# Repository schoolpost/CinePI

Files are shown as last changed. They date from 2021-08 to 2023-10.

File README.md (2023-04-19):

# CinePI V2: OpenSource Cinema Camera using Raspberry Pi
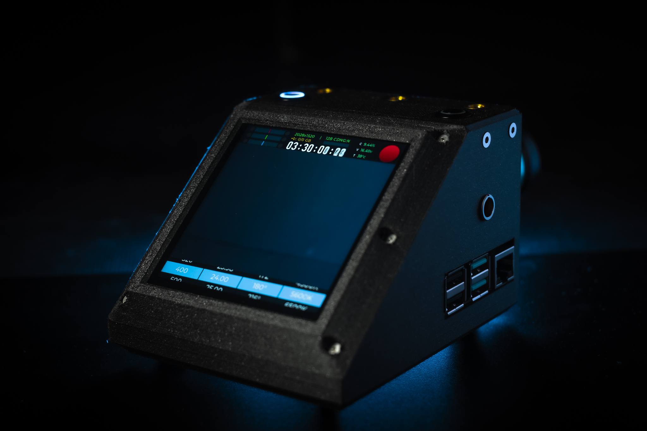
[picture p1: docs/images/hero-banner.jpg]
Banner

&nbsp;

# Introduction

The CinePI V2 is an OpenSource Camera design utilzing off-the-shelf / DIY hardware & software from vendors including: Raspberry Pi, Pimoroni, Adafruit, Sparkfun, etc...

The purpose of this repository and it's accomanying resocures is primarly to act as a template / starting point for your own design. CAD files are included for you to modify the enclosure to your needs, feel free to experiment with the parts used; use a different set of buttons, RTC, display, etc... the only components that cannot be changed are the Raspberry Pi 4B and the High Quality Camera Module. 

> ## Notice 
> 
> This design makes a number of modifications to hardware, as such is not recommended for those not comfortable with a soldering iron.
> 
> Warranties may be void. I am not responsible for any damages that accompany hardware modifications. 

# Features

- Super8 Sized Sensor ( Sony IMX477 )
- 12-bit CinemaDNG Recording
- 4.0" High Res Touch Screen Interface
- Internal High Capacity Battery 
- Real time clock 
- USB 3.0 External SSD Recording
- 1/4" Mounting Points
- 40mm Noctua Cooling System 

# Guide

Refer to the Wiki section for in-depth guide on hardware assembly and software installation. 

# References

CinePI Project Account | [Github Page](https://github.com/cinepi)

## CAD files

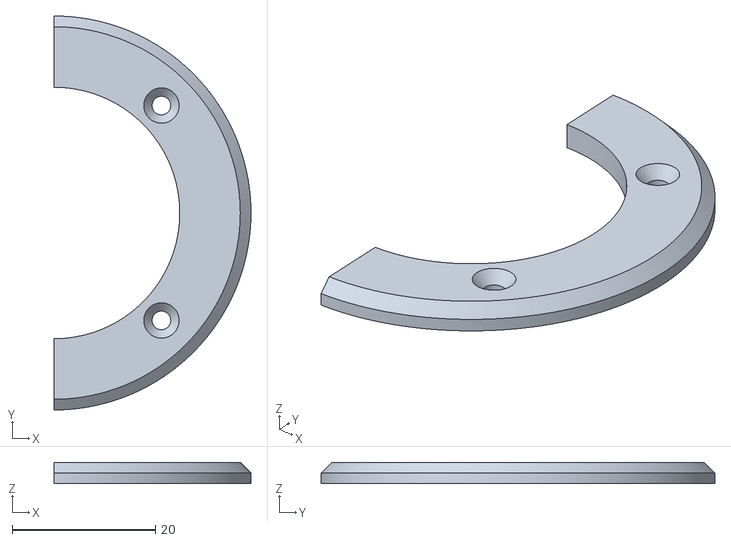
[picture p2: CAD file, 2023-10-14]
hardware/enclosure/turret_cover_plate_001.stl
27.5 x 55.0 x 3.00

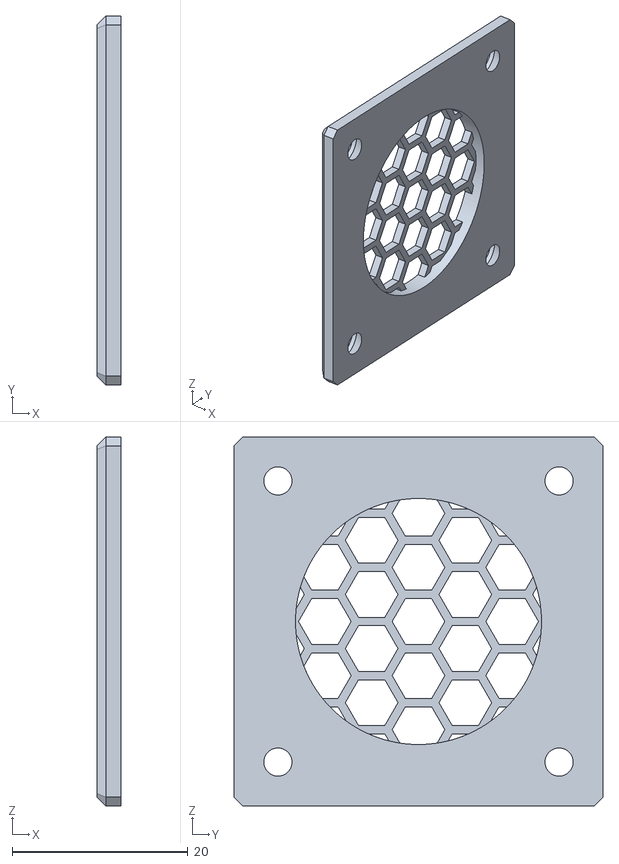
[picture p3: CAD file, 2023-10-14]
hardware/enclosure/fan_grill_001.stl
2.70 x 42.0 x 42.0

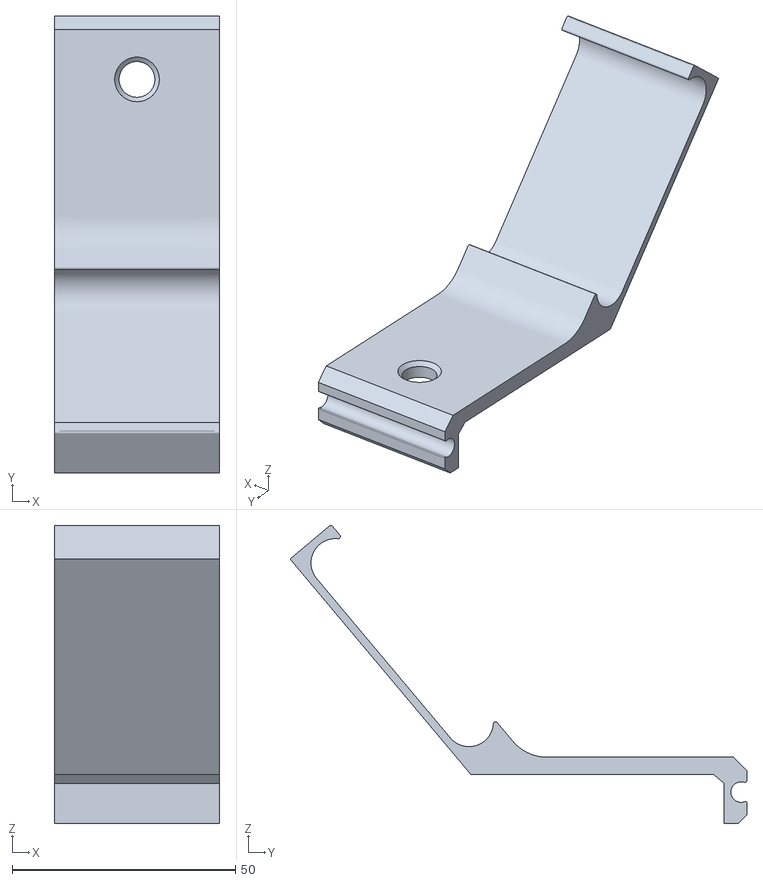
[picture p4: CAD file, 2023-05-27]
hardware/enclosure/t5_holder_001.stl
37.0 x 102.4 x 66.8

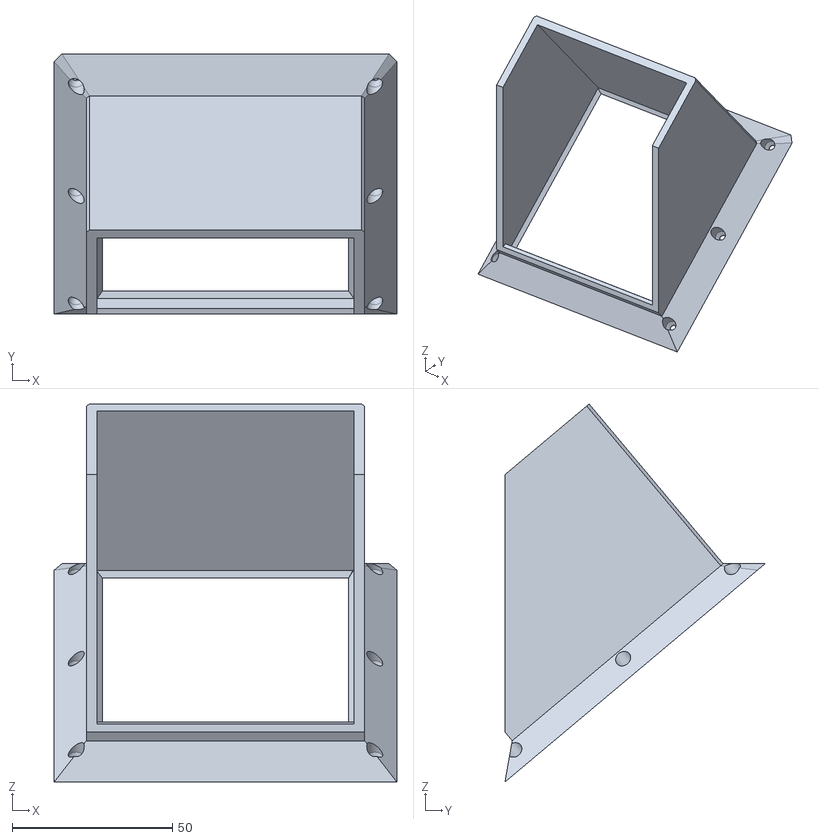
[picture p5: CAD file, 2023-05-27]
hardware/enclosure/sunhood_001.stl
106.8 x 81.1 x 117.8

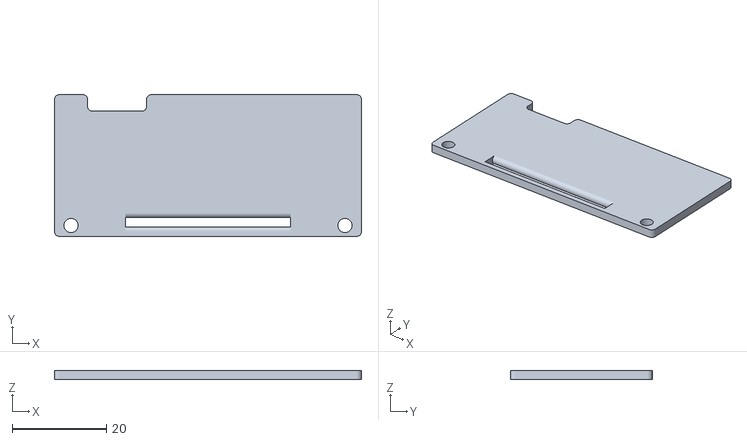
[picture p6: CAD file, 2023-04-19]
hardware/enclosure/ribbon_retention_bracket_002.stl
65.0 x 30.0 x 2.00

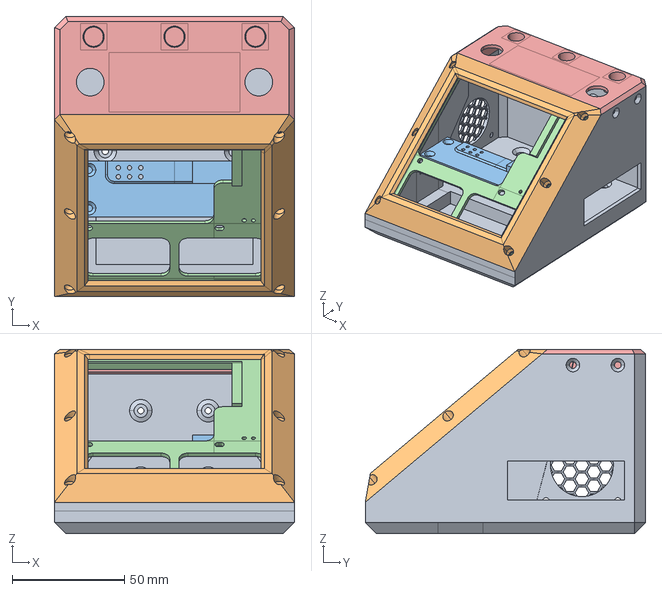
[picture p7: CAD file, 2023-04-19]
hardware/enclosure/CinePI_V2.stp
106.8 x 124.8 x 82.0 mm

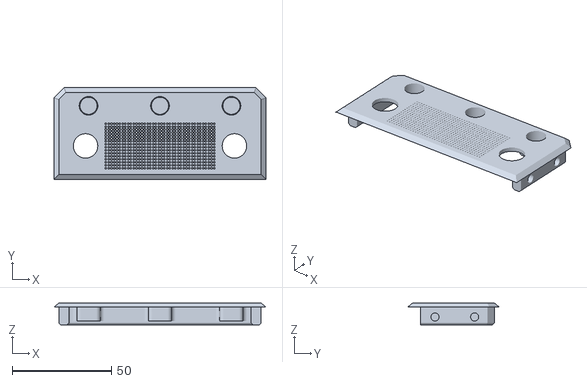
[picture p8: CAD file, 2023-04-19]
hardware/enclosure/top_plate_001.stl
106.8 x 46.1 x 11.0

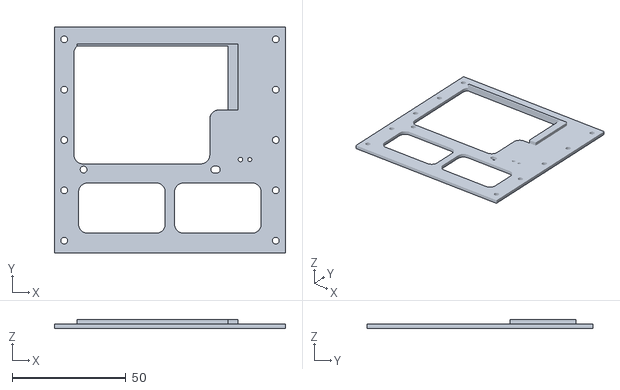
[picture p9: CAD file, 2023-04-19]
hardware/enclosure/hyperpixel_bracket_002.stl
101.6 x 99.6 x 4.00

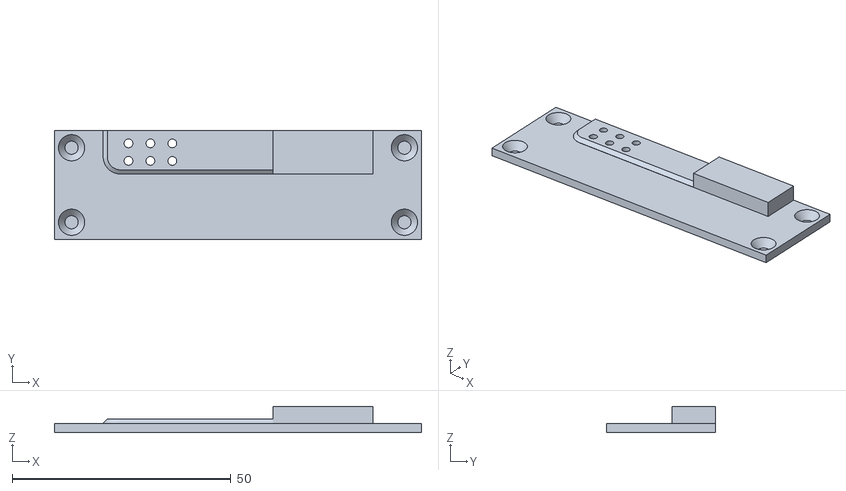
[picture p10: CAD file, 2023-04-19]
hardware/enclosure/battery_retention_plate_002.stl
83.8 x 25.0 x 6.00

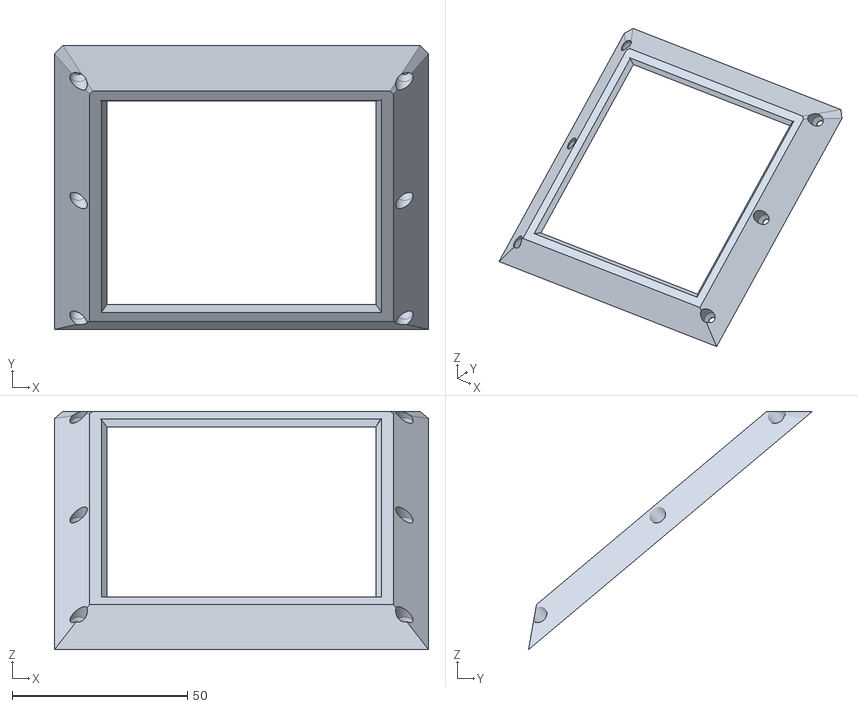
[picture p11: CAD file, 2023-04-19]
hardware/enclosure/screen_plate_001.stl
106.8 x 81.1 x 68.0

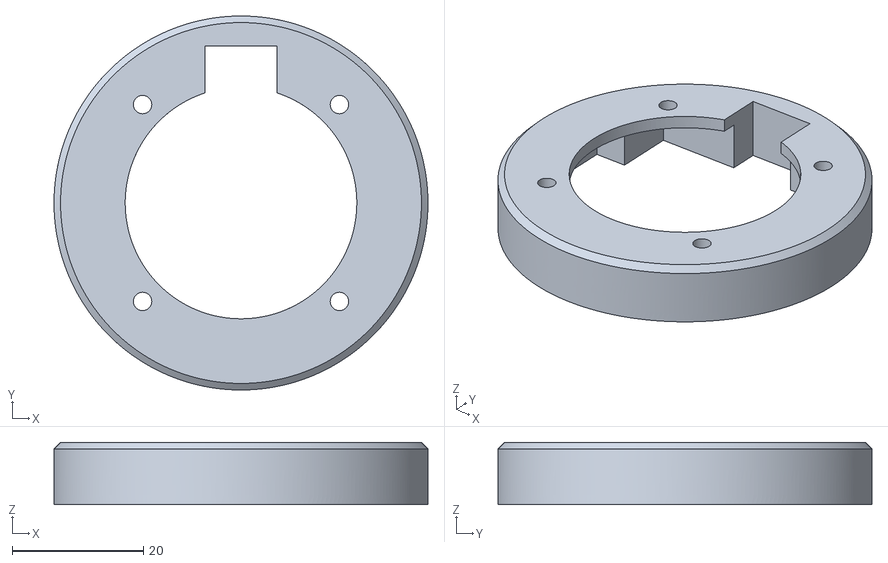
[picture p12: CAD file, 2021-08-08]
hardware/enclosure/cinepi_lens_turret_v1.stl
57.0 x 57.0 x 9.50

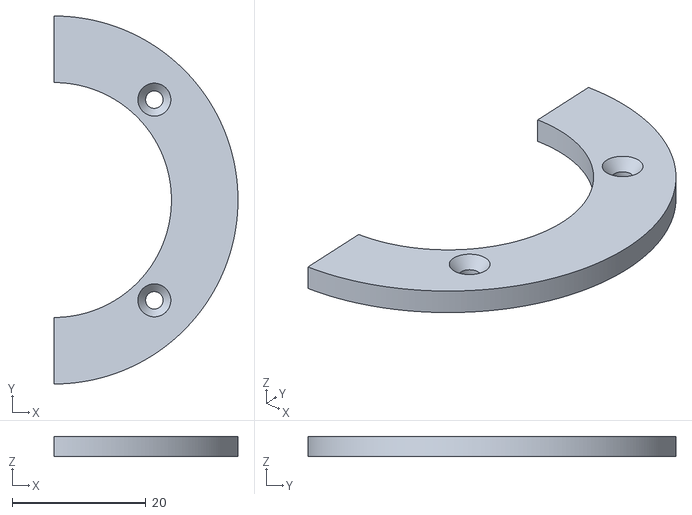
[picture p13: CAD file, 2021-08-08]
hardware/enclosure/cinepi_lens_turret_cover_right.stl
27.5 x 55.0 x 3.00

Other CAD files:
hardware/enclosure/cinepi_lens_turret_cover_left.stl

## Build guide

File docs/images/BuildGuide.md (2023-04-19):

| Item | Quantity | Link | Price |
|---|---|---|---|
| Raspbery Pi 2/4/8GB | 1 | https://www.digikey.com/en/products/detail/raspberry-pi/RASPBERRY-PI-4-MODEL-B-8G/12159401 | $35-$75 |
| Raspberry Pi HQ Camera | 1 | https://www.digikey.com/en/products/detail/raspberry-pi/SC0818/12339164 | $50.00  |
| Pimoroni Hyperpixel Square 4.0" | 1 | https://www.digikey.com/en/products/detail/pimoroni-ltd/PIM470/10329005 | $76.50  |
|  Zero2GoOmini R2 | 1 | https://www.digikey.com/en/products/detail/pimoroni-ltd/zero2go-omini-r2/15851372 | $22.00  |
| | | | |
| PCF8574 | 1 | https://amz.run/6bhj | $1.57 |
| PCF8523 | 1 | https://www.digikey.ca/en/products/detail/adafruit-industries-llc/3295/6238007 | $6.95 |
| CR1220 | 1 | https://amz.run/6bhs | N/A |
| | | | |
| Dupont Wires | | https://www.aliexpress.com/item/1005002000655439.html | |
| 40-pin FFC Cable | 1 | https://www.digikey.ca/en/products/detail/adafruit-industries-llc/4933/14291405 | |
| 40-pin GPIO FFC Extender Angled Male | 1 | https://www.digikey.ca/en/products/detail/adafruit-industries-llc/4904/14205155 | |
| 40-pin GPIO FFC Extender Angled Female | 1 | https://www.digikey.ca/en/products/detail/adafruit-industries-llc/4905/14205159 | |
| SparkFun QWIC Breakout | 2 | https://www.digikey.ca/en/products/detail/sparkfun-electronics/DEV-14495/7942483 | |
| QWIC Cables | | https://www.digikey.ca/en/products/detail/sparkfun-electronics/PRT-17260/13629028 | |
| | | | |
| Notcua NF-A4x10 5V 3-pin | 1 | https://amz.run/6bht | |
| 12mm Blue LED Button | 1 | https://www.aliexpress.com/item/33014419878.html | |
| 12mm Red LED Button | 1 | https://www.aliexpress.com/item/33014419878.html | |
| 7-pin LEMO Female | 1 | https://www.aliexpress.com/item/1005004949203075.html | |
| | | | |
| NCR18650B | 4 | https://www.18650batterystore.com/en-ca/products/panasonic-ncr18650b | |
| Micro JST connector/cable | | https://www.aliexpress.com/item/32704408939.html | |
| PVC Shrink | | | |
| 4S BMS | 1 | https://www.aliexpress.com/item/1005005389852465.html | |
| | | | |
| | | | |
| | | | |

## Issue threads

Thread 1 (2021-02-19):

Source Code?

eat-sleep-code, 2021-02-19:
Csaba --

I have been following your video examples on the Pi Forums and would love to incorporate your video capture logic into my own [camera program](https://github.com/eat-sleep-code/camera) (which has on screen controls, etc.).

I am currently printing Gen 3 of my camera which has a 5" hinged capacitive touch screen, top handle, multiple cold shoe mount screws, active cooling, and room for up to a 20,000mah battery.

schoolpost, 2021-02-28:
Check the releases section, just released the first alpha version. a lot of it is explained there.

peternewman, 2021-11-11:
Hi @schoolpost ,

On the latest release it says:

> source code will be available in the main repository. Due to the layers / complexity of creating a "Camera" through a traditional Operating system not every component of the software can be/will be referenced in the source. Filesystem drivers, boot configurations, etc.. are all examples of the additional layers that are required to make a functional camera and these layers will be left partially obfuscated from the source to reduce the number of dependencies and shear overall size of the code base. These components will be mentioned in documentation to give users the knowledge of their existence and how they can be modified/used.

Where is say the Python bmdproxy script currently being developed or the source code managed? What would someone open a pull request against if they wanted to make a change? I'm just curious about it, so don't want to have to download a 2GB file and flash it to a Pi or possibly mount it as loopback just to have a look at a few hundred kB of Python.

Closed 2021-03-06.

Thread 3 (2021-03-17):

Bluetooth control

pu3lkah, 2021-03-17:
Hi, I can't manage to connect the raspberry pi to my android device via bluetooth, is there anything I should configure on the board first ?

schoolpost, 2021-03-19:
What application are you trying to connect it with? You need to use an app that is designed for Blackmagic Cameras.

pu3lkah, 2021-03-20:
I'm using the control black magic camera app for android. Tom antos showcased it in one of his videos by using it with a bmpcc4k and it works flawlessly, but on my phone, as you can see I can only find one device (I'll add a screenshot) and I'm unable to pair to it, even after clearing the bluetooth and the app cache, restarting my phone and/or the pi, etc...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

schoolpost, 2021-03-22:
> I'm using the control black magic camera app for android. Tom antos showcased it in one of his videos by using it with a bmpcc4k and it works flawlessly, but on my phone, as you can see I can only find one device (I'll add a screenshot) and I'm unable to pair to it, even after clearing the bluetooth and the app cache, restarting my phone and/or the pi, etc...!
> [Edit, I also try formatting the sd card and reinstalling cinepi on it but the results are the same]

The Bluetooth service starts up when booted so nothing you have to do on the user side.

This will be something to look into, I was under the assumption most of these applications would connect with a similar procedure, but seems not to be the case. I do not have any android device to test with at the moment, so you may have to experiment /tinker with it yourself for the time being.

If you want to look at the source go to the controls-thread folder in the home directory of the installation.

pu3lkah, 2021-03-23:
Okay, thanks a lot, i'll try getting my hands on an ios device to test it out. Do you think there might be a way to control the settings with a wired controller ? Either mouse and keyboard or small arduino controller ?

nocantsin, 2021-05-08:
The Android app _My Camera Controller_ (gratis w/ ads) works with the CinePi:
https://play.google.com/store/apps/details?id=com.taskdesigns786.android.mycameracontroller&hl=en_US&gl=US

Leoba2700, 2021-06-22:
hi i have the same issue but with the bluetooth+ for Blackmagic app on my iPhoneX. I Cant find any raspberry bluetooth connection even in my bluetooth option. my raspberry pi 4 is brand new, there is nothing to activate in order to make it work ?

schoolpost, 2021-06-23:
> hi i have the same issue but with the bluetooth+ for Blackmagic app on my iPhoneX. I Cant find any raspberry bluetooth connection even in my bluetooth option. my raspberry pi 4 is brand new, there is nothing to activate in order to make it work ?

The Bluetooth service auto starts when the Pi is booted. I also use a iPhoneXR with Bluetooth+ and have not had the same issue you are having. Go to the Bluetooth settings of your iPhone and if you see your raspberry pi already paired, you should try to "forget device" maybe that will help.

Leoba2700, 2021-06-23:
that's weird... the thing is that the raspberry pi doesn't even show up in my bluetooth settings

nocantsin, 2021-06-23:
I am having the same issues - both the Android and the recommended iOS app.

schoolpost, 2021-06-23:
Will need to investigate this, may have been a change that happened on the IOS Application side that breaks compatibility.

Leoba2700, 2021-06-25:
is it possible to change the settings without the apps ? if yes, what is the way to do it ?

schoolpost, 2021-06-25:
> is it possible to change the settings without the apps ? if yes, what is the way to do it ?

Yes, you could create your own scripts that will control camera settings, but you will need to decide to use bluetooth, wifi or physicals controls to obviously interact with the Pi.

You need to look into v4l2-ctl

It's a command line utlity that allows you do control the settings of a v4l2 device ( /dev/video0 ) in this case. It's a bit more low level, you wont be changing "shutter speed" or "frame rate" but if you read up on what each does you should get an idea.

Leoba2700, 2021-06-25:
unfornatly I don't think I have the capacity to create my own script maybe ill try with an other app

schoolpost, 2021-06-25:
> unfornatly I don't think I have the capacity to create my own script maybe ill try with an other app

I have a development version that is newer than what is posted here on github, that one works just fine with Bluetooth+ app. I don't have time right now to upload it,  but I will try to do that soon.

Otherwise, yes your best luck would be to see if some other apps might work.

schoolpost, 2021-09-25:
Should be addressed in the latest 1.0.1 release. Please test and report back.

tallmansixfour, 2021-09-29:
Hey schoolpost,

having trouble connecting with any app on android. tried Control Blackmagic Camera (lost $12 - no returns), Blackmagic BlueConnect (goodbye $12), Blackmagic Camera control (free). tried clearing storage and cache on individual apps. nope. is there another cache to clean somewhere?

installed 1.0.1 Still shows v.1.0.0 Is something wrong here?
used 20210920_022913_pi_clone.img

I understand it's alpha, but could you test with one known-good Android app please?

thanks

Chris in Montreal

schoolpost, 2021-09-30:
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

Hi Chris,

Unfortunately I do not have any android devices to test with. Can you test with an iOS device?
This will help narrow down if it's a device specific problem or something else.

tallmansixfour, 2021-09-30:
thanks for the reply. i did try the free options first, but noting. My Camera Controller shows a device (code) then shows connecting and even initializing, but then nothing. paid options usually offer a refund for 5-10 minutes, but i the case of the two i mentioned, no such option was presented. im eager to get my project working with your system, raspivid pales in comparison. do you have a Patreon?

nils1976, 2022-01-24:
Hi guys,

First of all really cool project....
Managed to make that work in less than an hour? But also have the BT error.
My "camera" is also complaining, that it is v 1.0.0

I can connect to the pi via ssh. But was not able to find where the defaults are set. Therefore it is not usable at the moment.

How can I provide help to make the BT stuff work? Tried different apps und different platforms....(android and IOs)
but with no luck. Is there kind of an log? Didn't find that in /var/log....
where is the patreon link? or Paypal...? Think you need beer or coffe support!!

Also i doesn't work with the DSI-connected Display from raspberry...not a big thing, but maybe someone like to know.
It there a restriction in resolution?

But what I can say: Using a passive CSI to HDMI (not converting to HDMI!!!!!) adapter works fine with a 2m cable.
Which makes it also more intersting for independent filming, as you can put the "recorder" away from the head.
Like our plan is: putting the camera on a handlebar of a bike....having the recoder in the back or bag....;-)

kind regards Nils

schoolpost, 2022-01-24:
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

Very kind of you Nils, glad you can find a use case for this project.
You can donate to my paypal here:
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

As far a bluetooth control is concerned, It seems to me that only application that works right now is a paid app called "Bluetooth+" that is available on IOS. This is the app I did all my testing/development with. I did not realize that although I was reverse engineering a standard protocol, some applications do not seem to detect it.

The way you control the camera's settings is mostly through v4l2-ctl. You can ssh into the pi and list the available controls and mess around with them to see how it changes the image. But also I'm looking into a better way to do this.

I was recently looking to attach a display to the camera, over DPI using the GPIO pins; but even this proved to be a problem and it seems like the reason for this has to do with the i2c being used by the camera module and therefore it claims the i2c so no other peripheral that uses i2c can be used. ( simplification )

Would love to see some footage you film when you are done with your setup.

Csaba Nagy

tallmansixfour, 2022-01-24:
Thanks for the update. Made a donation - hope it helps. There is great
potential here. I want to use the setup for stereoscopic fiming.
Chris

On Mon., Jan. 24, 2022, 5:15 p.m. Csaba Nagy, ***@***.***>
wrote:

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

nils1976, 2022-01-25:
Ok now it is getting weird.....I was asking for a link to donate....some else donates....but I also....
I was using the bluetooth+ app at first time.....doesn't work....
Yes I can confirm, that it boots with DSI connected, can also see the overlay from the mmal stuff, than it runs into normal boot login, I think at the point where the sensor get initialized....anyhow....not a big thing, ordered a 7" Display yesterday.
If you are interested in getting i2c data, I have a little USB-analyzer...
So I will try the app again...it is always complaining the I should remove the camera from the bluetooth settings (can even put it in there, because it is not showing up in the OS....but in the app)

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
.

Let me know if I can do something from my side. Logs/debug output etc....

Btw: If I don't want to use XFS, what is the next best choice? Ntfs? or HFS?

If we can manage to get that work, you will get footage. Our apprentice will generate some....

nils1976, 2022-01-28:
Hey there,
is there a simple way to start the camera, lets say 2k 25p? I see that i can set the vertical blanking...but not shure if I exactly hit the 25p:  v4l2-ctl -d /dev/video0  --set-ctrl vertical_blanking=1500 gives me a 25p, not shure if this is on the point.......but I think it also depending on the resolution....I am not that python guy/programming guy, so a feedback would be nice..
I understood that your scripts reads the settings that are actual....an it is fine for me to set that manual, without using the app

Regards Nils

schoolpost, 2022-01-28:
> Hey there, is there a simple way to start the camera, lets say 2k 25p? I see that i can set the vertical blanking...but not shure if I exactly hit the 25p: v4l2-ctl -d /dev/video0 --set-ctrl vertical_blanking=1500 gives me a 25p, not shure if this is on the point.......but I think it also depending on the resolution....I am not that python guy/programming guy, so a feedback would be nice.. I understood that your scripts reads the settings that are actual....an it is fine for me to set that manual, without using the app
>
> Regards Nils

Hi Nils,

Yes, I also would need to review the code to confirm this, but I do believe it is the VBLANK that needs to be adjusted for this.

There is some more information about this here when I was also investigating how it works: https://forums.raspberrypi.com/viewtopic.php?p=1789990#p1789990

Regards,

Csaba Nagy

Closed 2023-04-19.

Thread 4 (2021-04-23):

Limited record time + weird files

pu3lkah, 2021-04-23:
Hi, so i have now been using your program for a few weeks on my raspberry/super 8 hybrid, and i love it. Apart from the bluetooth control on android I've already reported, i've ran into two other issues. The main one being that i cannot record more than approximately 40 seconds of video, and the more I record the shorter my record time get. At first i was using a cheap pny ssd, and I thought it might be that the drive wasn't fast enough. So I switched to a 500go samsung t7, which should be even faster than what the pi can output through usb 3 (i'm using a rpi 4b 4go ram), but i'm still running into the same issue. Both disks were formatted to exfat, I don't know if it comes from the disk or the board, if it should have more ram or if overclocking it a bit more might help. (I don't know if you ever ran into a similar issue, since in your video you're saying that you also are using a 4gb version)
The second one, which is not a big issue for me but i thought it might be worth letting you know, is that the files i record show as weird black images with color lines as if every file were corrupted (see screenshots) and it says that the image size is 128*67px. Also I cannont open it in premiere pro (it says "file not supported or damaged". But, where it get really weird, (but also the reason why I'm saying it's not a big issue) is that I can open the files in camera raw, and there i have all of my dng files, full size, perfectly fine, that i can then export in jpegs or png frame sequence. I have no idea what might be causing it, and i already tried re-flashing the sd card on the pi.
Thank you for your time and keep up the great work, it helped me tremendously in my projects ! I wish i could help with those issue, unfortunately i don't know much about programming. Hope those reports can help you fixing as many issues as you can in the future, and if i can do any tests for you than could be any help, let me know.
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

schoolpost, 2021-04-24:
Really glad you've found the project useful. If you have any footage you are willing to share, please do. Love to see how it's being used. You can post it on the raspberry pi forums if you are a member there: https://www.raspberrypi.org/forums/viewtopic.php?f=43&t=296776

To address your points, they are also issues I've faced myself.

The limited record time is the biggest hurdle because It's very complicated and a fix isn't exactly trivial. Yes a Fast SSD helps and I've tried many ( CFAST to USB3 adapter, Samsung T5 SSD, NVME to USB 3.0 adapter ) but these don't seem to be the actual bottleneck. It really comes down to how frames are being written to disk, which right now happens through write caching in RAM. That is why you have ~40seconds of record time ( 4GB model ) while for myself I have used the 8GB model and consitently get ~90seconds. So basically It seems the writing of the frames to disk is still not efficient enough, because as soon as the RAM get's full and it has to write to disk directly it is not fast enough. Not exactly sure how this can be addressed, but I'll be investigating asking around to see how it can be fixed.

The weird colored thumbnails is actually to be expected. Basically while this was in Alpha and especially while the Limited record time issue exists I didn't want to add any extra latency to writing a frame so I create an "empty thumbnail" so that is why it is kind of random. This is can be fixed with relative ease. But not looking to implement till the other issues are not solved.

schoolpost, 2021-04-28:
>  The main one being that i cannot record more than approximately 40 seconds of video, and the more I record the shorter my record time get.

May have solution soon, will keep you updated.

pu3lkah, 2021-05-20:
Thanks for all the updates, I actually tried formatting the disk in ext4, and I have much better record time. I haven't tested extensively yet, so I don't know what is the exact time limit, but with a samsung t7 in ext4, i was able to record clips up to 2 minutes. Probably would be able to record a bit more, haven't tried recording to its limits yet.

Tiramisioux, 2021-06-18:
Hi! Tried out the Samsung T7 500 MB drive in ext4 and was able to record a 24 minute clip @ 25 fps.

pu3lkah, 2021-06-18:
Nice to know it can be pushed so far ! Personally few minutes of clips at a time is fine by me. (Oh and I have the 4gb version so i probably wouldn't be able to record such long clips, I should test and see what the limitations are)

Tiramisioux, 2021-06-19:
I agree, a couple of minutes is enough. :) But recording now seems stable and consistent, which is a huge step forward!

Closed 2021-06-28.

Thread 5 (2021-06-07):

Unrecognized external SSD

jineshkunj, 2021-06-07:
Hello, thank you for making Cinepi
Please bear with me that my mother tongue is not English.

I cannot be identified successfully when I use both SSDs
One is Samsung T5 500g, the other is Lexar 500g
It should all be usb 3.1 specifications.

But I don't know why, the SSD cannot be recognized.
Excuse me, how can I solve this problem
Thank you very much, thank you :)

schoolpost, 2021-06-07:
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

When you format the SSD make sure the volume name is "RAW" otherwise it will not be mounted.

This will be changed in a later version so it can be anything.

Closed 2021-06-10.

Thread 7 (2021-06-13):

Lower ISO values than 100

Tiramisioux, 2021-06-13:
Is it possible to add lower ISO values to the available ones? Would like to try values 6,12 and 50. Can it be done solely in proxy.py, or do I have to manipulate other files as well?

schoolpost, 2021-06-13:
> Is it possible to add lower ISO values to the available ones? Would like to try values 6,12 and 50. Can it be done solely in proxy.py, or do I have to manipulate other files as well?

ISO, like many of the other controls is a computed value. If you wish to control it at the lowest level, ISO in this case would be the analouge_gain setting that is exposed by the V4L2 camera component. If my memory is correct, with the current way ISO is computed; 100 ISO is equal to 0 Analouge_gain. So 100 is the lowest ISO setting in this case.

You can look into the _v4l2-ctl_ utility to see how you can control the camera settings directly.

Proxy.py is essentially using that utility to set/get camera settings.

schoolpost, 2021-06-14:
This thread here may also be of some help in understanding how to control the camera through V4L2: https://www.raspberrypi.org/forums/viewtopic.php?f=43&t=281994&p=1789990#p1789990

Tiramisioux, 2021-06-14:
Thanks! Have been experimenting with v4l2-ctl and tried to change the multiplier in proxy.py from 100 to, for example 25 (for an ISO range of 25-556). But the camera still gives me 100 as the lowest ISO value. Am I understanding it correctly that this  could give an ISO range of 25 - 556?

schoolpost, 2021-06-14:
> Thanks! Have been experimenting with v4l2-ctl and tried to change the multiplier in proxy.py from 100 to, for example 25 (for an ISO range of 25-556). But the camera still gives me 100 as the lowest ISO value. Am I understanding it correctly that this could give an ISO range of 25 - 556?
>
> Or is the analogue_gain 0, giving a result similar to ISO 100 a limitation in the camera? That it's sensitivity can't be set to nil?

If you want to change the display of the ISO on the liveview you also need to change the render.c file in the mmal_ui_render folder. in that file is a gain_to_iso function you will need to change that to reflect your own calculation of ISO.

At the end of the day, the implementation I have in place is my best interpretation of how to calculate ISO.

Also read this: https://www.strollswithmydog.com/pi-hq-cam-sensor-performance/

Closed 2021-06-28.

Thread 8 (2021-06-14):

cinePI boot on terminal

eljuligallego, 2021-06-14:
Hi,

I setup the hardware as user guide says, flash sd connect HQ camera, connect "RAW" ssd and boot the 32GB sd card in a raspi 4 4GB.

after the cinePI splash screen the terminal appears. tried to start the terminal with the credential you provide and launched the python camera/cameracore3.py command but syntax errors appears.

It seems something it's not working on autostart. how should I continue to debug my hardware?.

Regards,
Juli.

schoolpost, 2021-06-14:
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

Have you verified that the camera works and the connection with camera to the PI is good? ( did you test it working before you tried CinePI? )

Otherwise, just in case I would possibly try to re-flash just in case something went wrong. Maybe a different sd card.

eljuligallego, 2021-06-15:
working, no idea what happened but now reconnect everything and boots.

Thanks.

schoolpost, 2021-06-15:
> working, no idea what happened but now reconnect and everything works and boots with video signal.
>
> Thanks.

Sometimes there can be kernel panics, it's the just nature of the project right now with it being in alpha.

Glad you got it up and running, I hope you can share some footage you film with it!

eljuligallego, 2021-06-15:
Thanks, I will!

Closed 2021-06-15.

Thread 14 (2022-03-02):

Serial control

willfromlondon, 2022-03-02:
This project has been incredible for some projects I've been working on. I'd love to be able to control basic settings (ISO/white balance/framerate/tint) from an arduino through the serial port - Is this something that's possible on this 1.0.1 release?

schoolpost, 2022-03-03:
> This project has been incredible for some projects I've been working on. I'd love to be able to control basic settings (ISO/white balance/framerate/tint) from an arduino through the serial port - Is this something that's possible on this 1.0.1 release?

This could be possible addition in the future yes, for consistency it would likely re-use the existing Blackmagic Camera Control protocol ( https://documents.blackmagicdesign.com/DeveloperManuals/BlackmagicCameraControl.pdf ) unless a better alternative is suggested.

casparmkerr, 2022-03-09:
I just discovered this amazing project, and I think physical control (ie through serial because of the lack of analog GPIO and i2c being used by the camera) would be a killer feature for making CinePi useful for less controlled environments!

I haven't ordered the necessary hardware yet as some further development seems to be needed to make the project useful "out of the box", and without the source code easily available (in addition to me really only having casual experience with python and java - no lower level code), I am not sure if I can really contribute much. That said, I'd be happy to give it a go if you found a practical way to share the source and not just builds!

willfromlondon, 2022-03-11:
Is recording in log format possible? The colour of the sensor is great but it would be awesome to get some more dynamic range.

Tiramisioux, 2022-03-12:
@casparmkerr Extra I2C can be achieved by assigning a new channel to two GPIO Pins

https://medium.com/cemac/creating-multiple-i2c-ports-on-a-raspberry-pi-e31ce72a3eb2

Working on a prototype for a CinePi HAT with physical controls - ISO, shutter angle, fps and manual speed ramping.

Doing some final tests now and will try to compile building instructions and code. But basically it is achieved by potentiometers > ADC converter > GPIO 26 (as SDA) and 5 (as SCL) > I2C > Raspberry Pi > Python script exectuting shell commands > v4l2-ctl settings.

Went down the HAT route for making a compact and sturdy solution, but the same thing could easily be achieved with a microcontroller and USB. First ideas I tried out was attaching a Microbit :) to the Pi for manual controls, sending data though USB to a Python script on the Pi executing shell commands.

Tiramisioux, 2022-05-26:
Is it possible to manipulate the basic Black Magic / Bluetooth Camera Control settings via the command line?

I have managed to control the v4l2-ctl settings directly using hardware peripherals (potentiometers etc) but I think a more elegant solution would be to reach them the same way the CinePi-system does.

Closed 2023-04-19.

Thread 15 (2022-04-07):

Start4x.elf compatibility

origilad, 2022-04-07:
Hi - relatively new pi user

I downloaded your latest release - flashed onto an sd card and booted up my Raspberry Pi 4 Model B - 8GB
On boot I get the error:
```start4x.elf: is not compatible```

I tried to debug on my own and updated all the files on the sd card with files from here: https://github.com/raspberrypi/firmware/tree/master/boot
(I think this is where I went wrong^)

Doing caused the pi to start booting - the CinePi splash screen would show for a couple of seconds and then crash and open a terminal. Seems like the camera wasn't detected by the OS.

Running ```vcgencmd get_camera``` or manually running raspistill both pointed to the camera not being detected.

I verified that the hardware/camera works - was able to run raspistill on the recommended Raspberry Pi OS.

Any ideas on what I should do?

schoolpost, 2022-04-09:
Hello,

I would recommend you try re-flashing, perhaps with a different sd card, or try with the different flashing utility.

Also try the first release of the firmware and see if that changes anything.

Tiramisioux, 2022-05-08:
Have the same problem. Seems to be an issue with newer Raspberry Pi:s.

Found this thread: [https://forums.raspberrypi.com/viewtopic.php?t=282764](https://forums.raspberrypi.com/viewtopic.php?t=282764) and tried using the SD card in an older RPi 3, doing
```
sudo apt update
sudo apt full-upgrade
```
and then move it to the new RPi4. Got the same result as @origilad, with the Pi booting, showing splash screen and crashing into terminal. In the list of "OKs", it says:

_[FAILED] Failed to start Load Kernel Modules
See systemctl 'status system-modules-load.service' for details_

schoolpost, 2022-05-08:
>

Thanks for looking into this, I will look into solutions.

chapop, 2022-07-01:
Hi, i have the same problem. Perhaps a new release of Cinepi with a more recent OS compatible with the last raspberry firmware could solve it?
Unfortunately i don't know how to do that, is it possible?

Tiramisioux, 2022-08-08:
Also had problems installing the 32-bit version of Rasbian o on my new Pi 4. 64-bit version worked fine though. Maybe this has something to do with it?

Polyrhythm, 2022-08-19:
I also am hitting this problem with a new Raspberry Pi 4 8gb, newly setup.

schoolpost, 2022-08-19:
> I also am hitting this problem with a new Raspberry Pi 4B 8gb, newly setup. Flashed using the recommended app for OSX.

Noticed on the Raspberry Pi Forums you were able to resolve the issue, I sure those who may run into the issue in the future would appreciate knowing how to work around this If you are willing to share.

Polyrhythm, 2022-08-20:
Yep! I did manage to resolve this with my newer Raspberry Pi 4B board.
@origilad, you were close with your thinking, but instead of copying _all_ the files from that boot folder, what you want to do is just copy over anything that is starts with `fixup` or `start`. Replacing the other files is unnecessary.

Once you do that, you should have no problems starting up CinePi.

Tiramisioux, 2022-10-09:
@Polyrhythm - van confirm that only files `fixup4_` and `start4_` (8 files total) need to be replaced for fix to work.

Closed 2023-04-19.

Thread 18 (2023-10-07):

Additional information needed on lenses/adapters

beesterman, 2023-10-07:
This build guide is in depth enough for someone that doesn't know what they are doing to build it. However, after handing over the repo to my less tech savy friend they struggled to answer the following questions:

- ### Lenses used in build guide
After some searching neither of us were able to find the type of lense that was used in the build guide aside from some related links of digikey
- ### Other common/cheap lenses options
 After some digging into the discord we found some potential options but some additional guidance on what other lenses outside of what was used in the guide would be nice. Especially because some of the best promo material for the project uses massive lenses but no info provided.
- ### Additional information about the specifics for mounting various lenses
The sensor that you linked states that it fits C mounts by default. However the datasheet on digikey is broken. Going to the raspberry Pi official page states that the lense comes with a CS adapter. So this might be confusing for new people and a good reason to provide more info on the lenses and mounting options. Also the sensor housing/adapter that you linked appears to be different from the one used in the build guide.

I really love this project and I think this could be a amazing option for amateur photographers or just people wanting to DIY something. If I could contribute I would but I hope this might provide some insight to improve your wiki even further!

schoolpost, 2023-10-07:
Thanks for the feedback! Yes, the current build guide is incomplete and a ( long time ) work in progress. I will try my best to address the points you have highlighted.

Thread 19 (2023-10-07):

Add ability to take stills

catdogmat, 2023-10-07:
It would be awesome if you could take still photos with this camera. Please consider adding a button for photos and possibly settings for shutter speed and iso.

schoolpost, 2023-10-08:
Yes, taking still frames as .DNG file is possible; but is not fully implemented in the cinepi framework yet.

mrjohnc, 2023-10-17:
Adding this function might help encourage more people to take part in the project, there are a large number of open source people interested in photography and open source cameras

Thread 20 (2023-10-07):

HDMI output possible?

TychoWerner, 2023-10-07:
Hi, I would like to use this in live production, is it possible to have a clean feed from the HDMI?

schoolpost, 2023-10-08:
Yes, you can make the preview image go out through HDMI. However, as of the current state; I have not been able to do simultaneous LCD preview + HDMI output ( only 1 or other. ) It should be possible but needs more development work make it possible.

TychoWerner, 2023-10-08:
Ah okay, that is fine for my use case as I usd external monitors anyway

Op zo 8 okt. 2023 02:39 schreef Csaba Nagy ***@***.***>:

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

lsdave, 2023-10-19:
Being able to control the camera using CEC over HDMI like how blackmagic does would be cool as well.

PeteHaughie, 2025-01-21:
@TychoWerner you could try a HDMI splitter and feed it from the 5v GPIO pin.

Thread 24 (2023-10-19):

Would it be possible to add on board scene lighting ?

jerrynsr, 2023-10-19:
It  would be useful to have onboard scene lighting and the ability to control onboard / external lighting from the UI.

The reason why I'm mentioning this is I'm planning on building the CinePI to replace my old Cannon 1080p Camcorder and hopefully  make some development contributions to the project.

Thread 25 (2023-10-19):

Has anyone tested C-Mount to Pentax K mount  with Pentax K lenses and this camera rig for backfocus ?

jerrynsr, 2023-10-19:
I'm getting pretty excited about this project.   I found C-Mount to Pentax K mount adapters on Fotodiox.  This means I can use my Vintage Pentax K lenses with this rig.  Has anyone tested the back focus with the Raspberry PI HDCAM ?

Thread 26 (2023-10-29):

License

AndreaMonzini, 2023-10-29:
Hello,

great project !

I kindly ask why you changed the license from GPL to CC-BY-SA ?
I think that GPL license is more for software while creative commons for creative contents.
But in my opinion the most important difference is that with GPL there a clear distinction of the output:

https://www.gnu.org/licenses/gpl-faq.html#WhatCaseIsOutputGPL

for example Blender use GPL license but the output like rendering, animation and video do not have to follow the GPL license.
In the case of CC BY SA , the output video from the CinePi project should be restricted to same  CC BY SA license ?
Because with the CC BY SA license there is not the output distinction.

I am not a lawyer, just a free and open source supporter, but from my point of view the GPL license seems more appropriate.

Anyway very interesting project !
Thank you !

schoolpost, 2023-10-29:
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

Hi Andrea,

This repository only contains the CAD/3D models for the CinePI V2 camera I designed; which is more appropriately licensed with CC-BY-SA, and the underlying software is hosted in a separate repository: https://github.com/cinepi/cinepi-raw and linked to within this repo.

AndreaMonzini, 2023-10-29:
Hello,
thank you for the answer.
about the license i was referring to the alpha release software as a disk image of this repository:

https://github.com/schoolpost/CinePI/releases

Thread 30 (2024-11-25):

Housing for 18650 Batteries and other Model Changes

rileymintable, 2024-11-25:
While I deeply enjoy the spirit of a truly totally open-ended project, there are a few issues/rough patches with the 3D model files provided. I understand the quickness of the build but as the project is recirculating around RPi Magazine, maybe it's time to take a moment for revision? The last revision was a year ago!

1: the housing for 18650 batteries is either too shallow or too narrow. I cannot decide which. The 4S BMS from Ali is no longer available nor are there any immediate replacements for a BMS that small. The next best option is the "4PCS 4S 30A 12.8V 18650 Lithium Iron Phosphate Battery Protection Board" from AITIAO (???). If any one has a better alternative it would be much appreciated to find a smaller BMS without purchasing a ton of mismatches since the specs can be hard to come by. 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

2: Next is the ability for an on/off switch and external power input slot. Curious as to how you will actually plug the thing in once you go through the battery acrobatics. As it stands, you need to basically file off layers of the open area for RPi USB slots and wire a switch and port to plug power into. It works but it's not elegant.  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

I am NOT an expert at STL file manipulation but AM willing to try. Scaling the HyperPixel mount holes is the biggest concern, so maybe someone has provided a workaround or different 3D model to print a variant house for the V2 it would be greatly appreciated!

Sorry for the word salad as I am not on here often for discussion but hopefully this can kick off something cool.

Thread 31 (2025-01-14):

Fixed / wall-powered studio camera build (4K 30fps)

geerlingguy, 2025-01-14:
I have been looking for ways to optimize my studio setup for YouTube recording for years. A CinePi camera would not only be one way to make my workflow better—it would be extremely fitting to record videos about Raspberry Pis... _on a Raspberry Pi_ :)

The features I would like (in order of importance):

  - Ability to get decent depth of field (to make background a few feet behind me slightly blurred while I'm sharp)
  - 4K 30 fps output (either HDMI or SDI)
  - Remote control ability (ideally be able to have it boot quickly, and either have Home Assistant integration or just output automatically over HDMI)

In a studio setting, I have a lot of control over lighting, color, focal distance... which should make some of the controls needed for handheld/field operation unnecessary.

I currently have the following sensors available to build around:

  - Raspberry Pi HQ Camera (IMX477 - 7.9mm diagonal)
  - Arducam Klarity (IMX283 - 15.86mm diagonal, used in @will127534's [OneInchEye](https://github.com/will127534/OneInchEye))
  - Arducam Darksee (STARVIS 2 IMX678 - 8.86mm diagonal)

And of course I have a number of Pi 5s and CM5s to use.

DM115-rpi-win, 2025-01-16:
4K30 would be nice, but I think there is a significant hardware limitation that keeps it from recording up to 4k. Looking at the specs for the Sony IMX477 directly from Sony's website [https://www.sony-semicon.com/files/62/pdf/p-13_IMX477-AACK_Flyer.pdf](url) suggests that the sensor itself doesn't have the bottleneck, so its either the pcb for the camera, or the Pi. Considering that we only conlcluded this with the Raspberry Pi 4, there is a chance that it would be possible.

schoolpost, 2025-01-16:
I can confirm that 4K is possible with the Raspberry Pi HQ camera module + Raspberry Pi 5. ( requires a customized version of the IMX477 driver as referenced here: https://github.com/raspberrypi/linux/pull/6208 )

Recording is whole other story, I haven't tried doing any H264 encoding of the 4K. It is possible 4K MJPEG can be done and also 4K can be output via the HDMI to be recorded via an external recorder.

The ISP itself can more than adequately handle the 4K sensor data.

Carnarts, 2025-01-16:
Yes it's working and has been enabled to test by running:

`sudo rpi-update pulls/6208  `

and adding overlay

`dtoverlay=imx477,pi5`

and disabling this

`camera_auto_detect=1`

Although I've not tested it much so far.

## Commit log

2021-06-07 Added lens section + some bugfixes and improvements
2021-08-08 Inital release of 3D CAD / STL files for 3d printed case
    [cinepi_case_body_v1.stl, cinepi_case_cover_v1.stl, cinepi_case_v1.stp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]
2023-04-18 revising for next release.
    [cinepi_case_body_v1.stl, cinepi_case_cover_v1.stl, cinepi_case_v1.stp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]
2023-04-19 README started, CAD / STL's added
    [CinePI_V2.stp, battery_retention_plate_002.stl, hyperpixel_bracket_002.stl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]
2023-05-27 added sunhood and t5 holder models
    [sunhood_001.stl, t5_holder_001.stl]
2023-10-14 sensor turret .stl files added
    [cinepi_lens_turret_cover_left.stl, cinepi_lens_turret_cover_right.stl, cinepi_lens_turret_v1.stl]
